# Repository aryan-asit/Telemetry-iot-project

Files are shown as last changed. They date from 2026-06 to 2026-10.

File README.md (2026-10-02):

# 4-Layer IoT Telemetry Board

A custom 4-layer IoT Telemetry Board designed from scratch using KiCad. The board is built around an ESP32 and integrates environmental sensing, local data storage, USB connectivity, wireless communication, and battery charging and power management in a compact PCB.

## Project Overview

The goal of this project was to design a compact and reliable IoT hardware platform capable of collecting environmental data, processing it locally, storing telemetry data, and communicating wirelessly.

The project covers the complete PCB development workflow, from component selection and schematic design to PCB layout, verification, 3D inspection, and manufacturing file generation.

## 3D PCB View

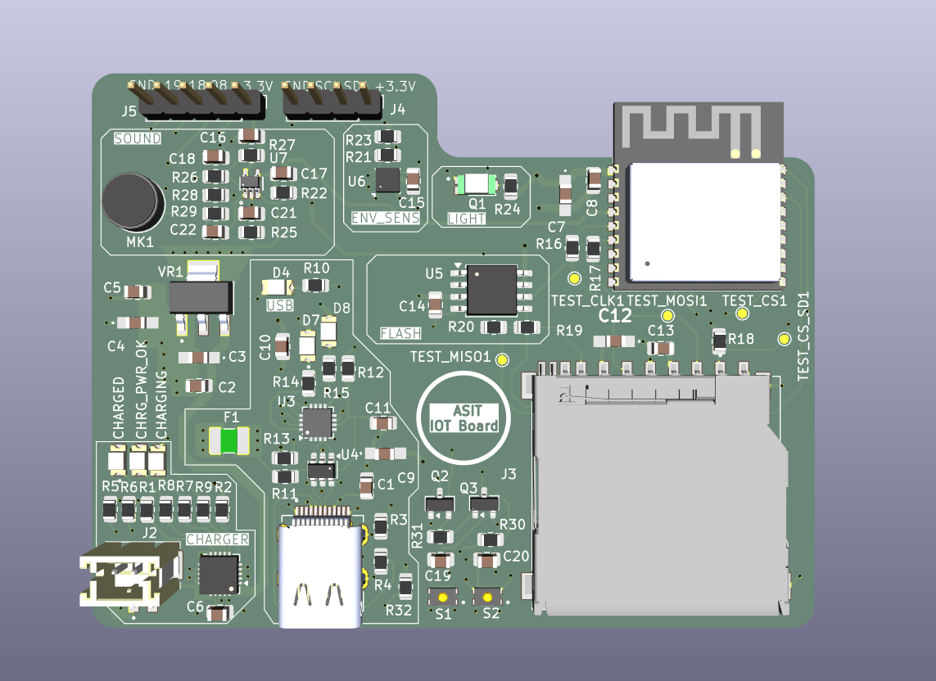
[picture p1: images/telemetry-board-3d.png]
3D View of ASIT IoT Board


## Key Features

### ESP32 Processing and Connectivity

The ESP32 is the main controller of the board and provides:

- Sensor data acquisition
- Local data processing
- Wi-Fi connectivity
- Bluetooth connectivity
- Communication with external peripherals

### Sensors

The board includes multiple sensing elements for environmental and acoustic monitoring:

- Microphone for sound sensing
- Humidity sensor for environmental monitoring
- Ambient light sensor for light-level measurement

### Data Storage

Two storage options are integrated into the board:

- Micro SD card for removable and higher-capacity data storage
- Flash memory for local non-volatile storage

### Power Management

The power section is based on the MCP73871 battery charging and power-management IC.

Main power features include:

- USB Type-C power input
- Battery charging
- Power-path management
- Battery-powered operation
- Dedicated 3.3 V regulation using an LM1117-3.3V regulator

### USB Type-C

A USB Type-C connector is included for power input and USB communication.

## PCB Stack-Up

The board uses a 4-layer PCB stack-up to improve power distribution, grounding, and routing flexibility.

| Layer | Purpose |
|---|---|
| Layer 1 | Signal |
| Layer 2 | Ground Plane |
| Layer 3 | Power Plane - 5 V and 3.3 V zones |
| Layer 4 | Signal |

The dedicated ground and power layers provide continuous return paths and simplify power distribution across the board.

## Communication Interfaces

| Interface | Purpose |
|---|---|
| I2C | Sensor and peripheral communication |
| SPI | SD card, flash memory, and other peripherals |
| USB | Power, programming, and communication |
| Wi-Fi | Wireless connectivity |
| Bluetooth | Short-range wireless connectivity |

## System Architecture

```text
                         +---------------------+
                         |     USB Type-C      |
                         |    Power / USB      |
                         +----------+----------+
                                    |
                                    v
                         +---------------------+
                         |      MCP73871       |
                         | Battery Charging &  |
                         |   Power Management  |
                         +----------+----------+
                                    |
                                    v
                         +---------------------+
                         |     LM1117-3.3V     |
                         |  Voltage Regulation |
                         +----------+----------+
                                    |
                                    v
                    +------------------------------+
                    |             ESP32            |
                    |      Processing & Control    |
                    |                              |
                    |       Wi-Fi + Bluetooth     |
                    +--------+----------+----------+
                             |          |
                 +-----------+----------+-----------+
                 |                      |           |
                 v                      v           v
          +-------------+       +-------------+ +---------+
          |   Sensors   |       |   Storage   | |  USB    |
          |             |       |             | | Type-C  |
          | Microphone  |       | Micro SD    | |         |
          | Humidity    |       | Flash       | |         |
          | Light       |       |             | |         |
          +-------------+       +-------------+ +---------+
```

## PCB Design Workflow

### 1. Concept Development

Defined the requirements for a compact IoT telemetry platform covering sensing, processing, storage, communication, and power management.

### 2. Component Selection

Selected the ESP32, sensors, memory devices, charging IC, regulator, connectors, and supporting components based on the system requirements.

### 3. Schematic Design

Designed and reviewed the complete circuit schematic and connected the individual functional blocks.

### 4. Footprint Selection and Creation

Selected suitable KiCad footprints and created or customized footprints where required.

### 5. PCB Layout

Defined the 4-layer stack-up and placed components while considering board size, routing complexity, signal paths, power distribution, and component accessibility.

### 6. Routing

Routed signal, power, and communication connections with attention to return paths, grounding, and clean power distribution.

### 7. 3D Verification

Configured 3D models and inspected the complete board to verify component placement and the overall physical arrangement.

### 8. ERC and DRC Verification

Performed Electrical Rules Check (ERC) and Design Rules Check (DRC) to identify and resolve schematic and PCB design issues.

### 9. Manufacturing Output

Generated Gerber and other required manufacturing files for PCB fabrication.

## Design Highlights

### 4-Layer PCB Design

The dedicated ground and power layers provide better power distribution and more flexible signal routing than a basic 2-layer approach.

### Integrated Power Management

The MCP73871 handles battery charging and power-path management, while the LM1117-3.3V provides a regulated 3.3 V supply for the low-voltage circuitry.

### Multiple Peripheral Interfaces

The board combines sensors, storage, USB, and wireless communication on a single PCB, making it suitable for different embedded and IoT applications.

### Compact Functional Layout

The component placement and routing were optimized to balance board size, functionality, accessibility, and routing complexity.

## Repository Contents

```text
Telemetry-iot-project/
|
+-- IOT_PCB/
|   +-- KiCad schematic and PCB design files
|
+-- images/
|   +-- telemetry-board-3d.png
|
+-- schematic files.pdf
|   +-- Complete schematic documentation
|
+-- Screenshot *.png
|   +-- PCB design and layout screenshots
|
+-- README.md
|   +-- Project documentation
```

## Tools and Technologies

### Hardware

- ESP32
- Microphone
- Humidity sensor
- Ambient light sensor
- Micro SD card
- Flash memory
- MCP73871
- LM1117-3.3V
- USB Type-C

### PCB Design

- KiCad v10
- Schematic Capture
- PCB Layout
- Footprint and Symbol Management
- 3D PCB Visualization
- ERC
- DRC
- Gerber Generation

### Communication

- I2C
- SPI
- USB
- Wi-Fi
- Bluetooth

## Applications

The board can be adapted for applications such as:

- Environmental monitoring
- IoT sensor nodes
- Wireless telemetry
- Data logging
- Noise monitoring
- Ambient light monitoring
- Smart embedded systems
- Battery-powered IoT devices
- Hardware prototyping

## What I Learned

This project provided practical experience in:

- 4-layer PCB design
- Schematic design and verification
- Component selection
- Footprint management
- PCB placement and routing
- Power distribution and grounding
- Signal-integrity considerations
- ERC and DRC debugging
- 3D PCB inspection
- Gerber generation
- Iterative hardware design and debugging

One of the main design challenges was finding the right balance between board size, routing complexity, power distribution, component placement, and overall functionality.

## Future Improvements

Possible future improvements include:

- Additional environmental sensors
- Cloud-based telemetry
- OTA firmware updates
- Improved power optimization
- Additional communication interfaces
- Dedicated debugging and programming features
- Enclosure and mechanical integration
- Web or mobile dashboard for telemetry visualization

## Author

**Aryan Asit**  
B.Tech - Electronics and Communication Engineering  
VLSI and Embedded Systems  
Indian Institute of Information Technology Manipur

## Repository

GitHub: https://github.com/aryan-asit/Telemetry-iot-project

## License

Refer to the repository license for usage and redistribution terms.

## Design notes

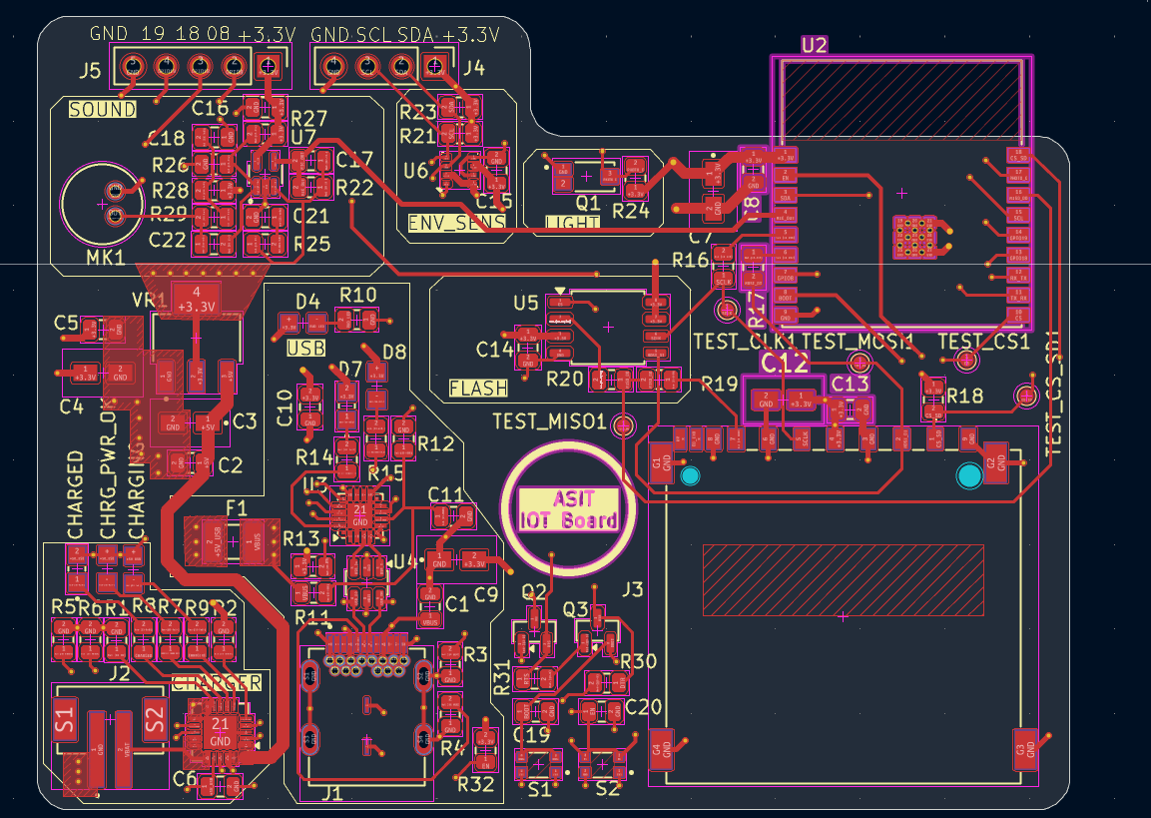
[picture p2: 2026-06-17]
images/Screenshot 2026-06-17 125201.png

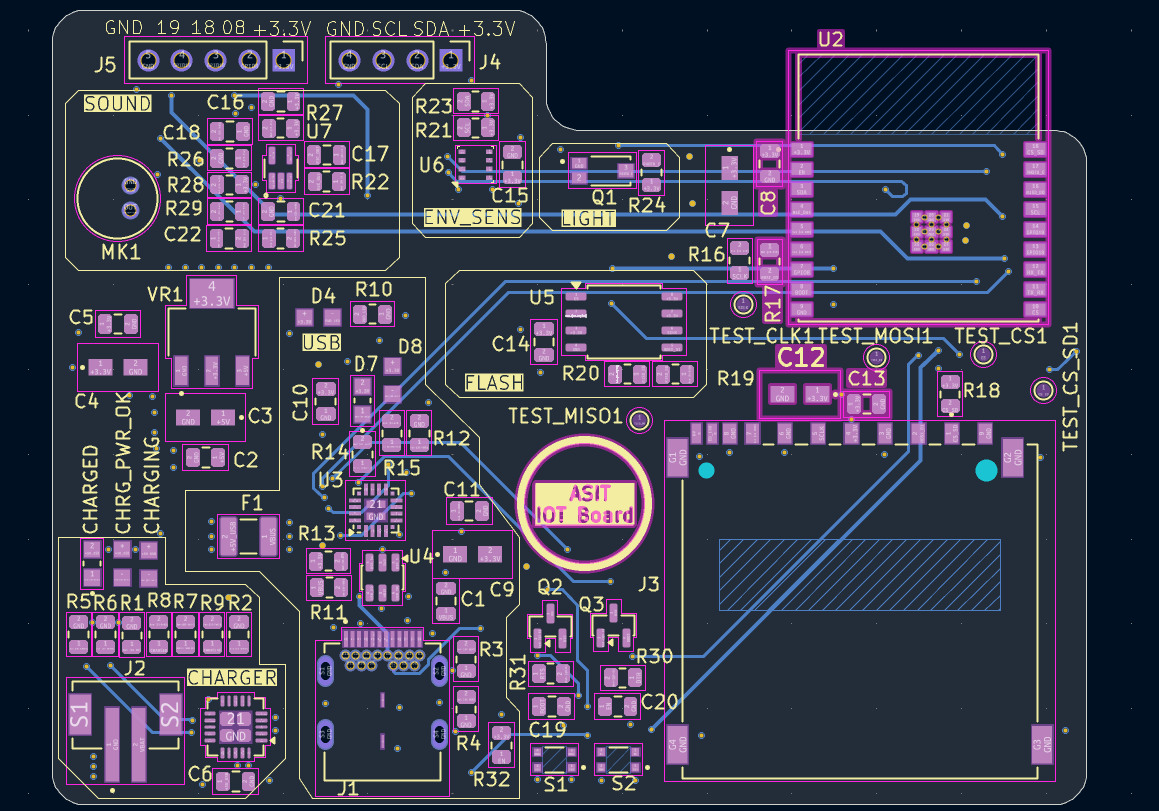
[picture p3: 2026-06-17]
images/Screenshot 2026-06-17 125239.png

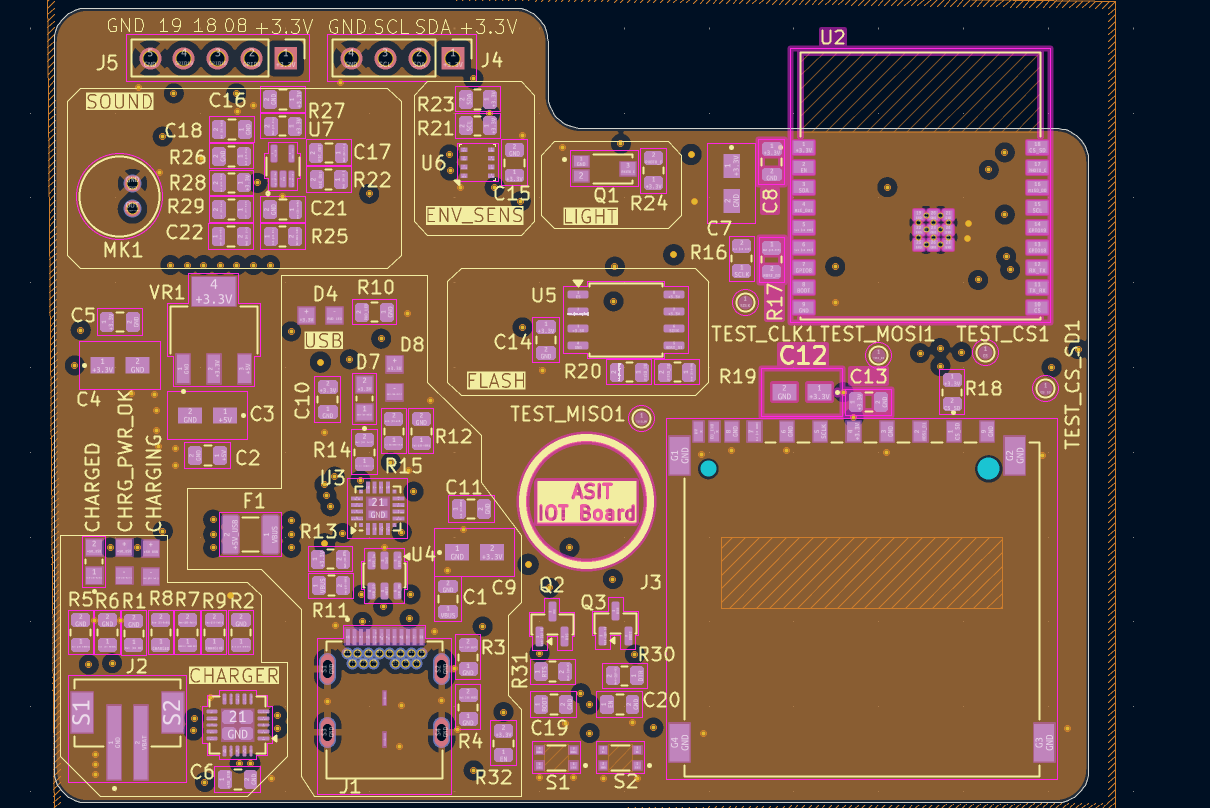
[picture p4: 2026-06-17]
images/Screenshot 2026-06-17 125227.png

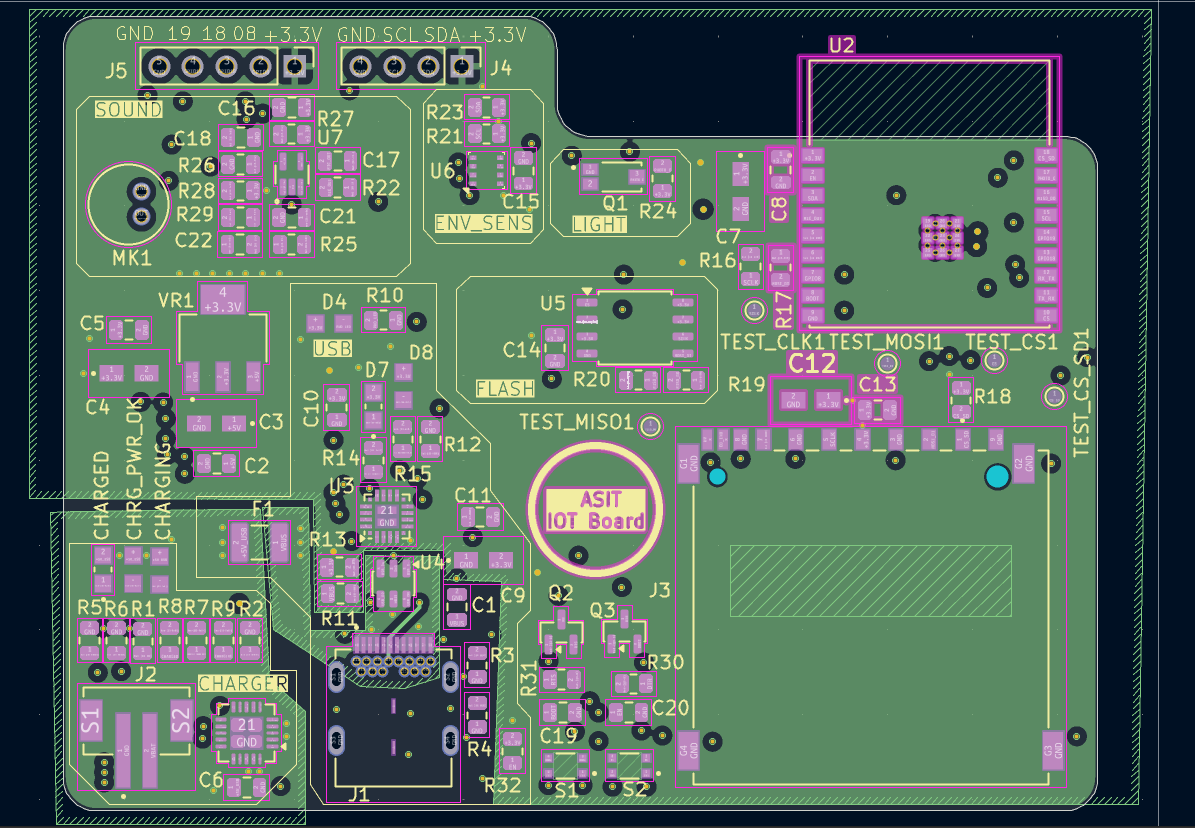
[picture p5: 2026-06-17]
images/Screenshot 2026-06-17 125213.png

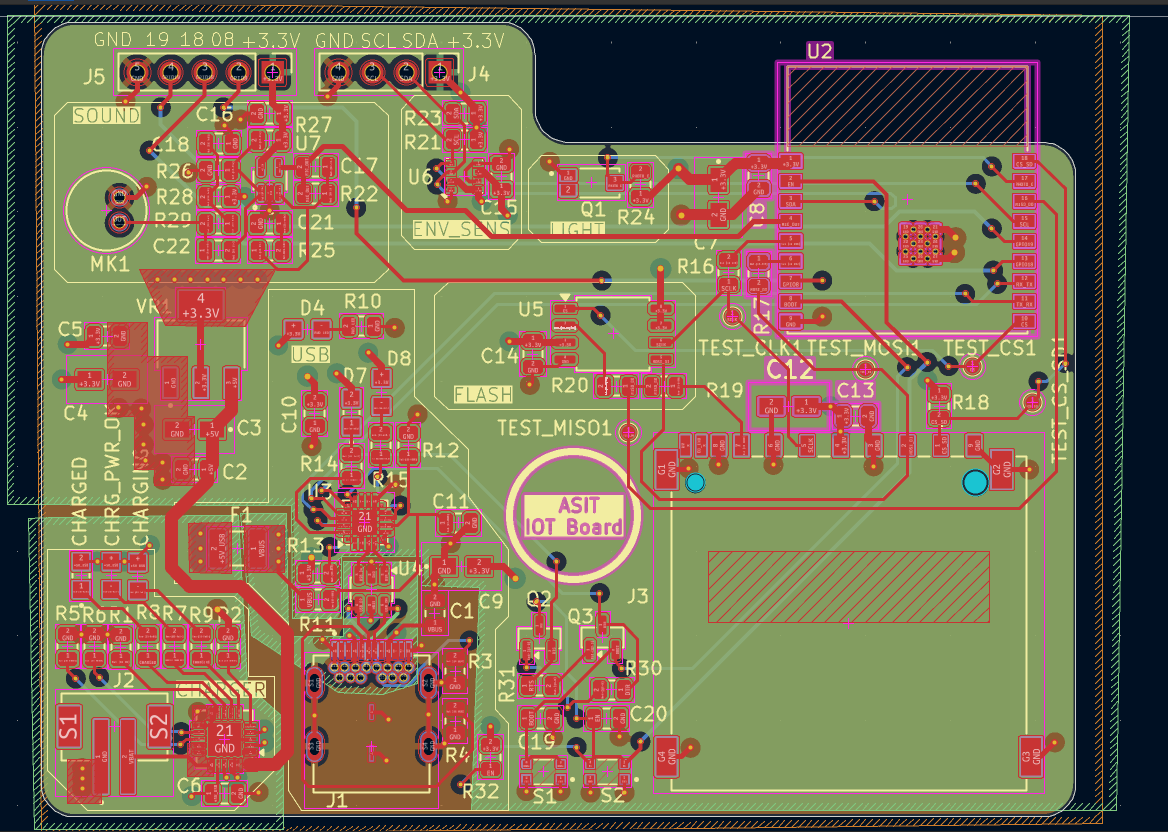
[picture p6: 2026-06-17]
images/Screenshot 2026-06-17 125148.png

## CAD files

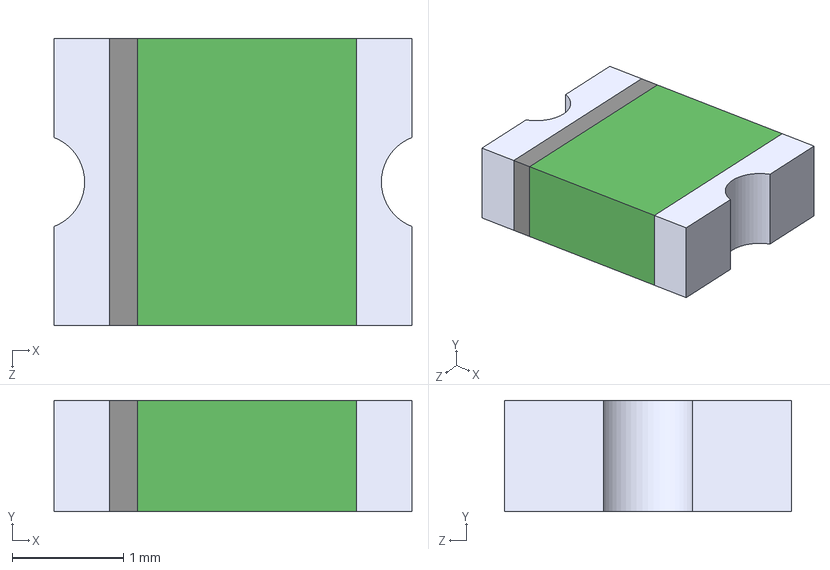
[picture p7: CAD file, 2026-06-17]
IOT_PCB/footprints_and_symbols/0ZCH0110AF2E/0ZCH0110AF2E.step
3.21 x 1.00 x 2.58 mm

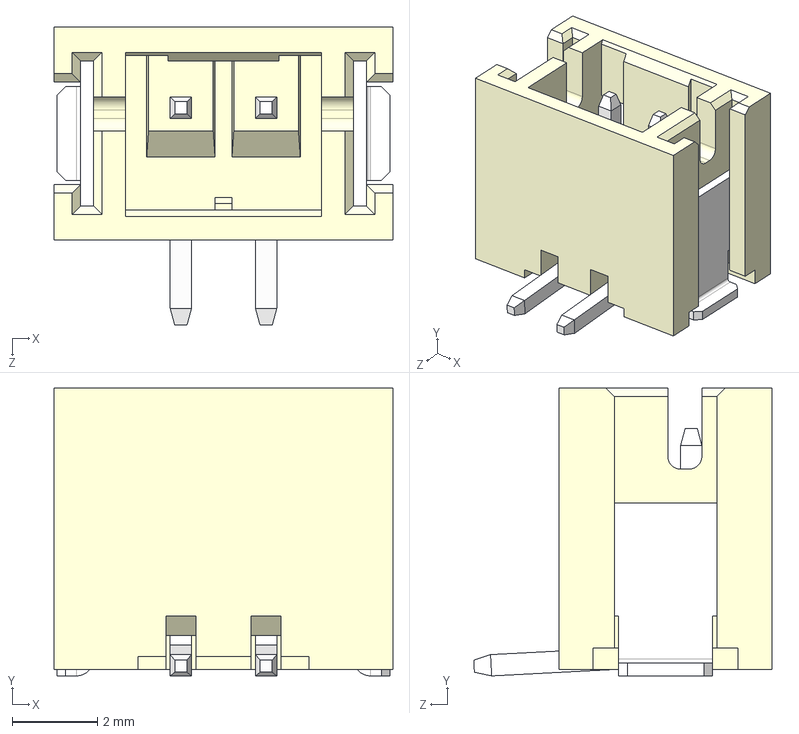
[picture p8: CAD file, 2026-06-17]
IOT_PCB/footprints_and_symbols/B2B-PH-SM4-TB/B2B-PH-SM4-TB.step
7.95 x 6.75 x 7.00 mm

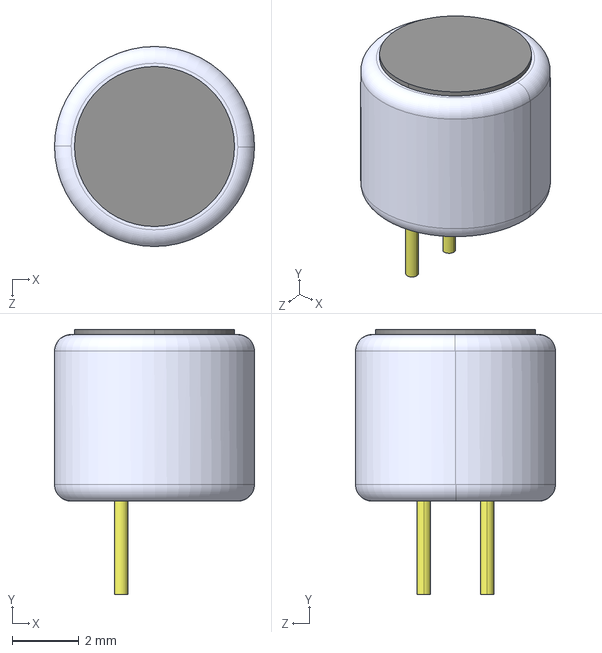
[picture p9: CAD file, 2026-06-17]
IOT_PCB/footprints_and_symbols/CMC-5042PF-AC/CMC-5042PF-AC.step
6.00 x 7.95 x 6.00 mm

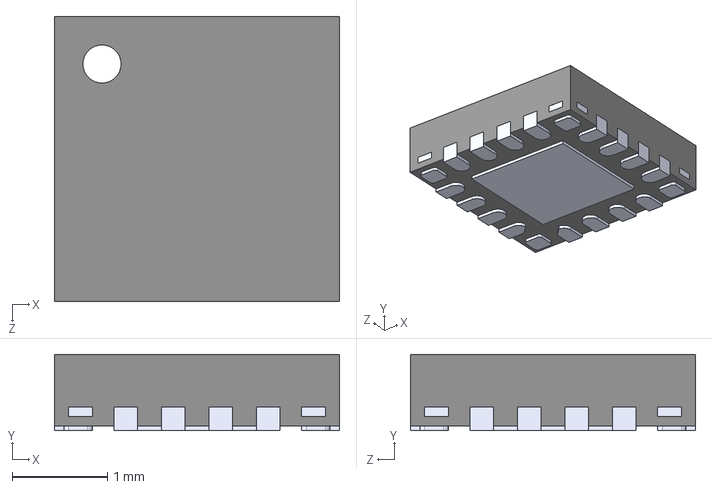
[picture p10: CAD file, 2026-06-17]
IOT_PCB/footprints_and_symbols/CP2102N-A02-GQFN20/CP2102N-A02-GQFN20.step
3.00 x 0.8 x 3.00 mm

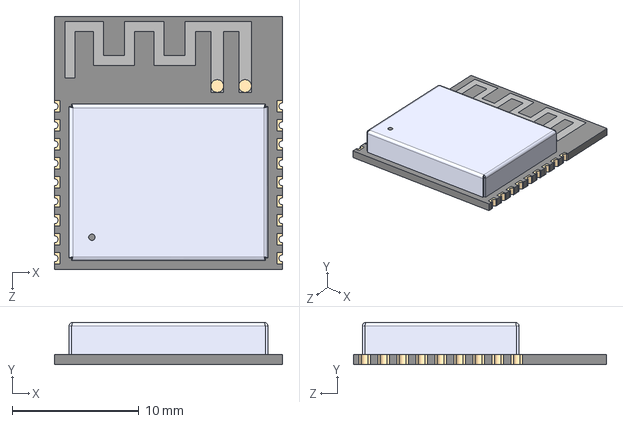
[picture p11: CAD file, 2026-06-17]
IOT_PCB/footprints_and_symbols/ESP32-C3-WROOM-02-H4/ESP32-C3-WROOM-02-H4.step
18.0 x 3.35 x 20.0 mm

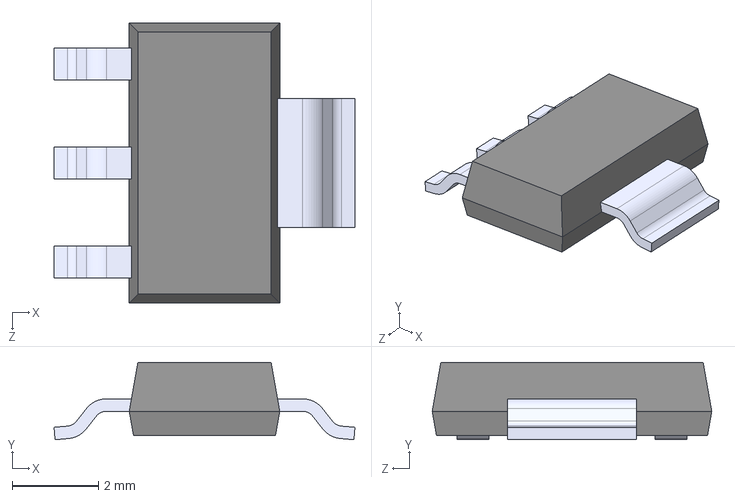
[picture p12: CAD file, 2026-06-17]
IOT_PCB/footprints_and_symbols/LM1117MPX-3.3/LM1117MPX-3.3.step
7.00 x 1.80 x 6.50 mm

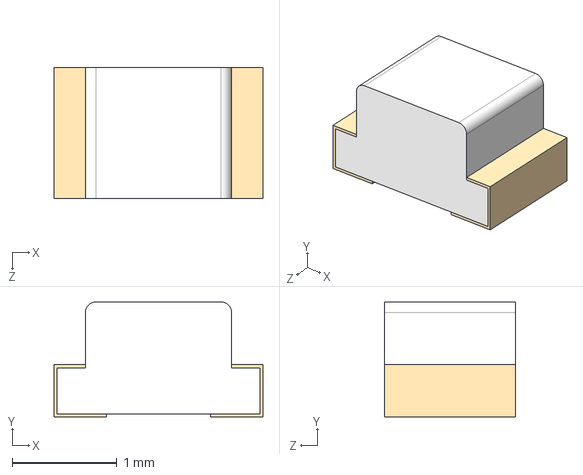
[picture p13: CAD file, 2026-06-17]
IOT_PCB/footprints_and_symbols/LTST-C170GKT/LTST-C170GKT.step
2.00 x 1.10 x 1.25 mm

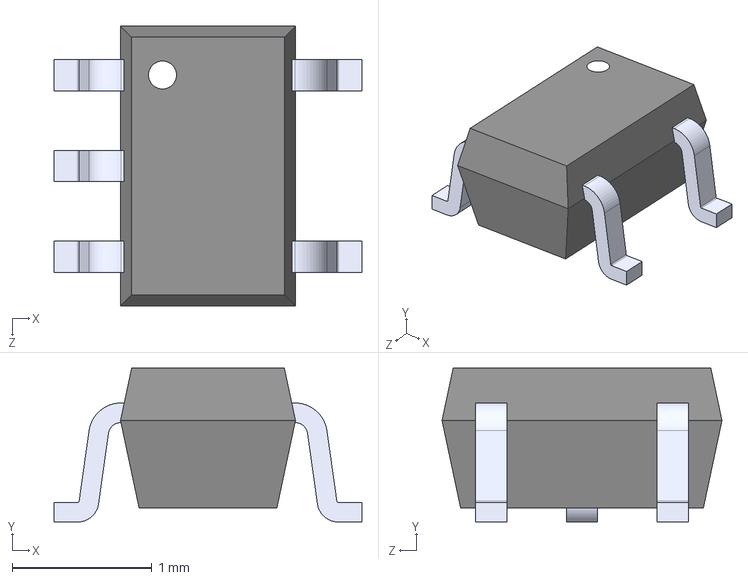
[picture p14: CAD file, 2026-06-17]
IOT_PCB/footprints_and_symbols/MAX4466EXK/MAX4466EXK.step
2.20 x 1.10 x 2.00 mm

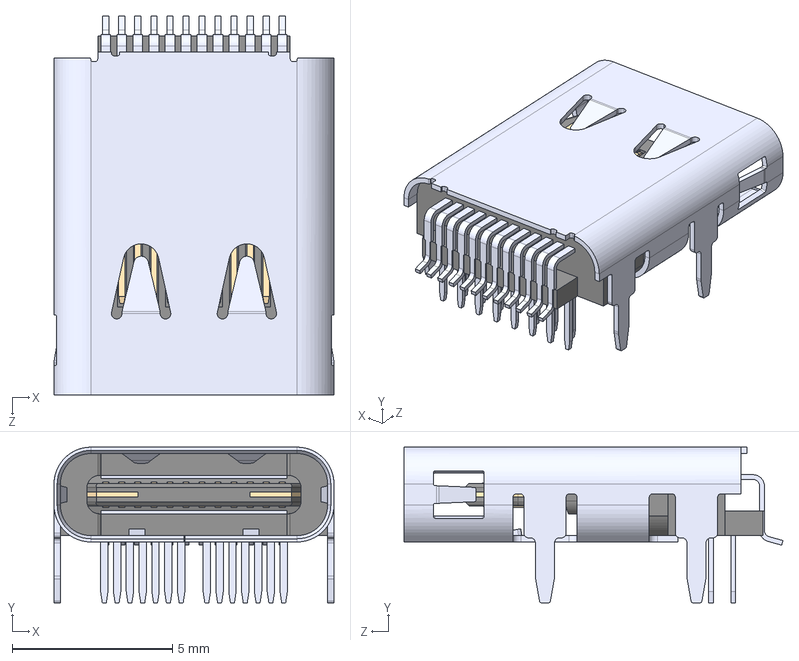
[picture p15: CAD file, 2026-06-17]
IOT_PCB/footprints_and_symbols/SS-52400-003/SS-52400-003.step
8.74 x 4.86 x 11.8 mm

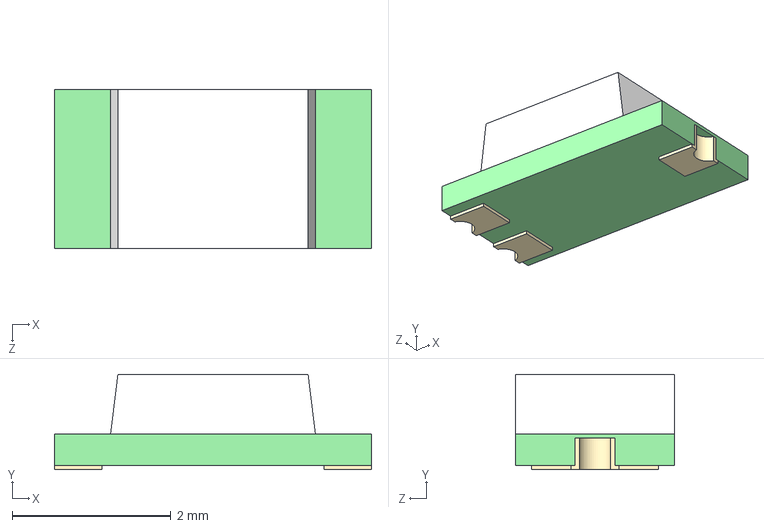
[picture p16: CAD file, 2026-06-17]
IOT_PCB/footprints_and_symbols/TEMT6000X01/TEMT6000X01.step
4.00 x 1.20 x 2.00 mm

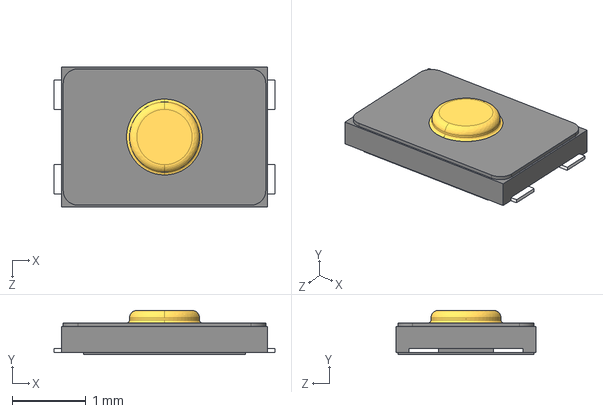
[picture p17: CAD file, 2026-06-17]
IOT_PCB/footprints_and_symbols/USLPT2819DT2TR/USLPT2819DT2TR.step
3.00 x 0.6 x 1.90 mm

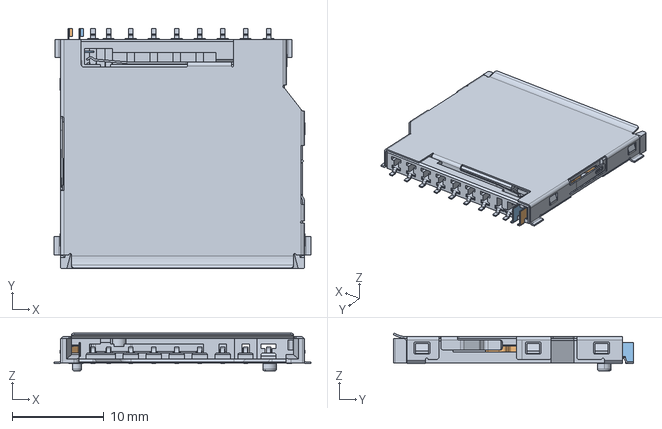
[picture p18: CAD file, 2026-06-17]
IOT_PCB/footprints_and_symbols/GSD090012SEU/GSD090012SEU.step
28.0 x 26.2 x 4.13 mm

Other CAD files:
IOT_PCB/footprints_and_symbols/LM1117MPX-3.3_NOPB/LM1117MPX-3.3_NOPB.step

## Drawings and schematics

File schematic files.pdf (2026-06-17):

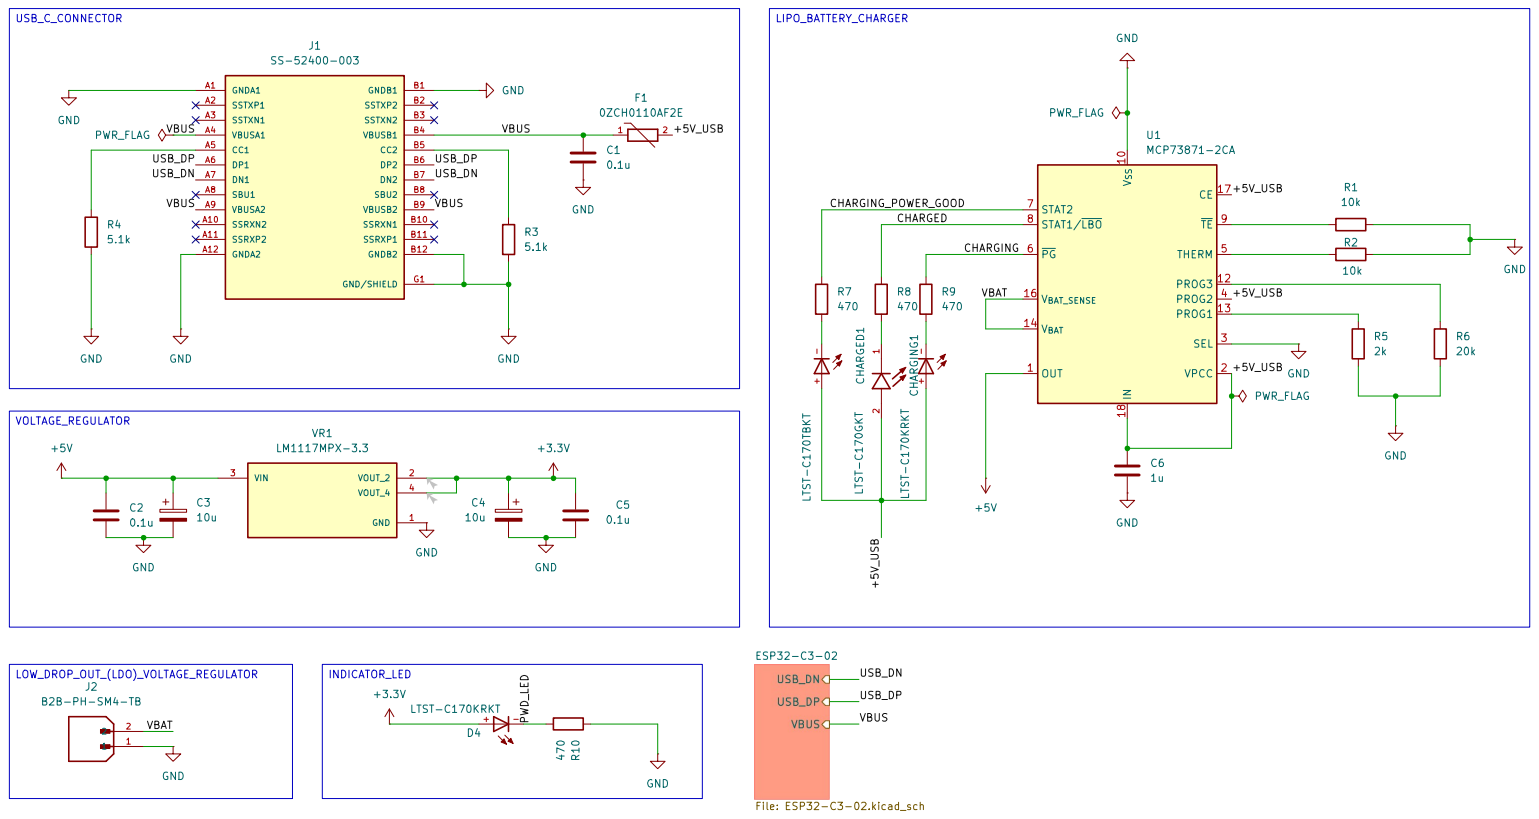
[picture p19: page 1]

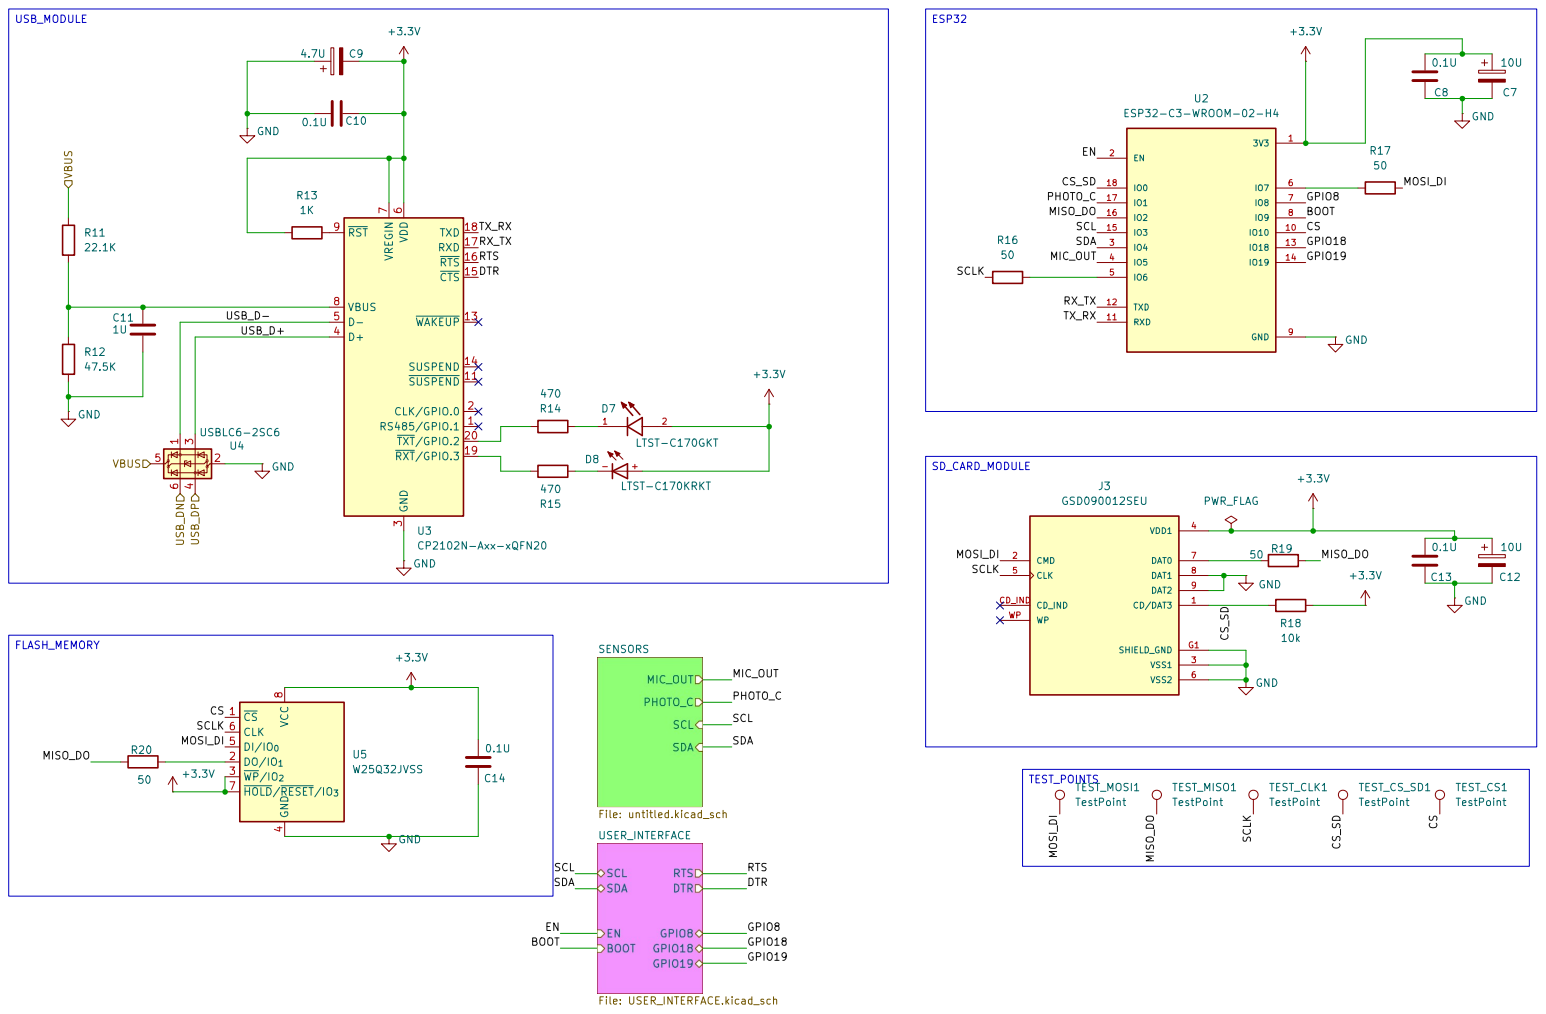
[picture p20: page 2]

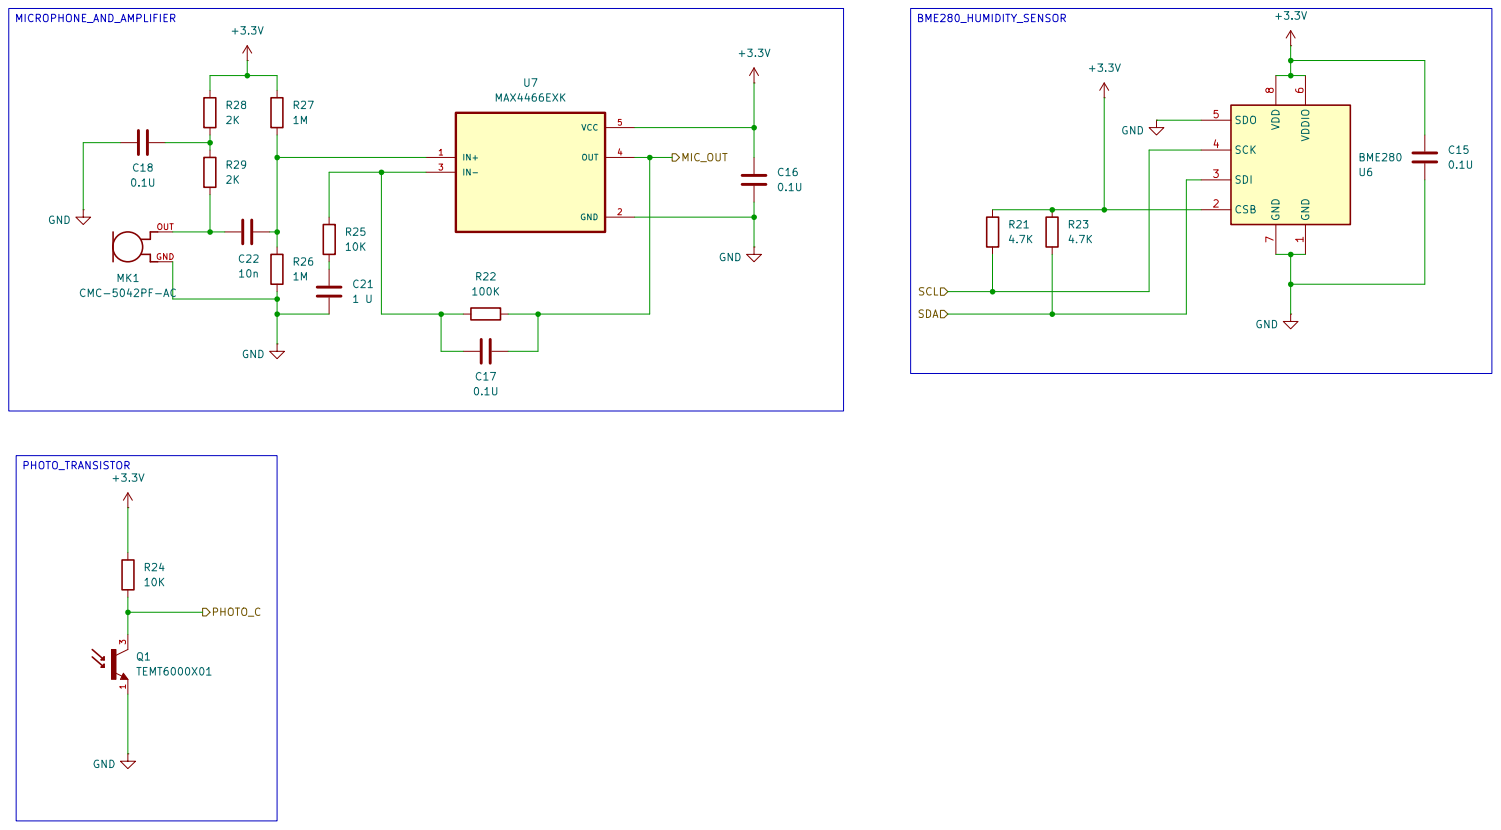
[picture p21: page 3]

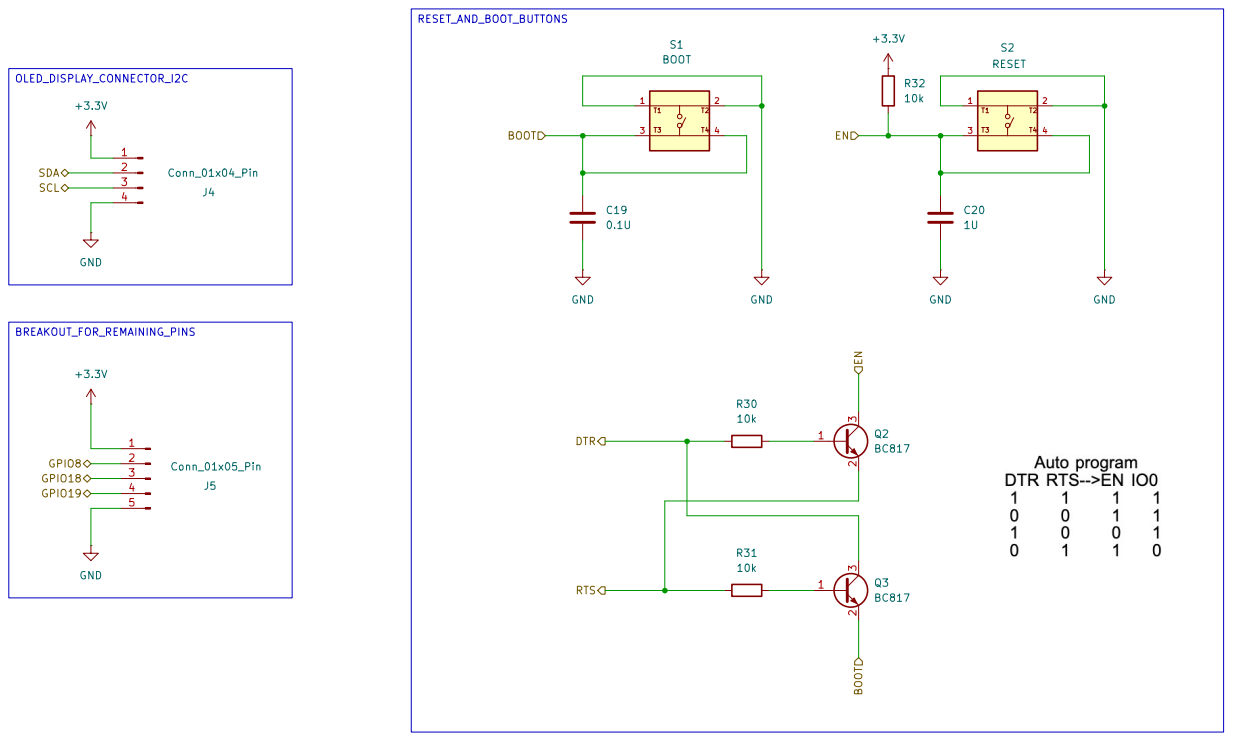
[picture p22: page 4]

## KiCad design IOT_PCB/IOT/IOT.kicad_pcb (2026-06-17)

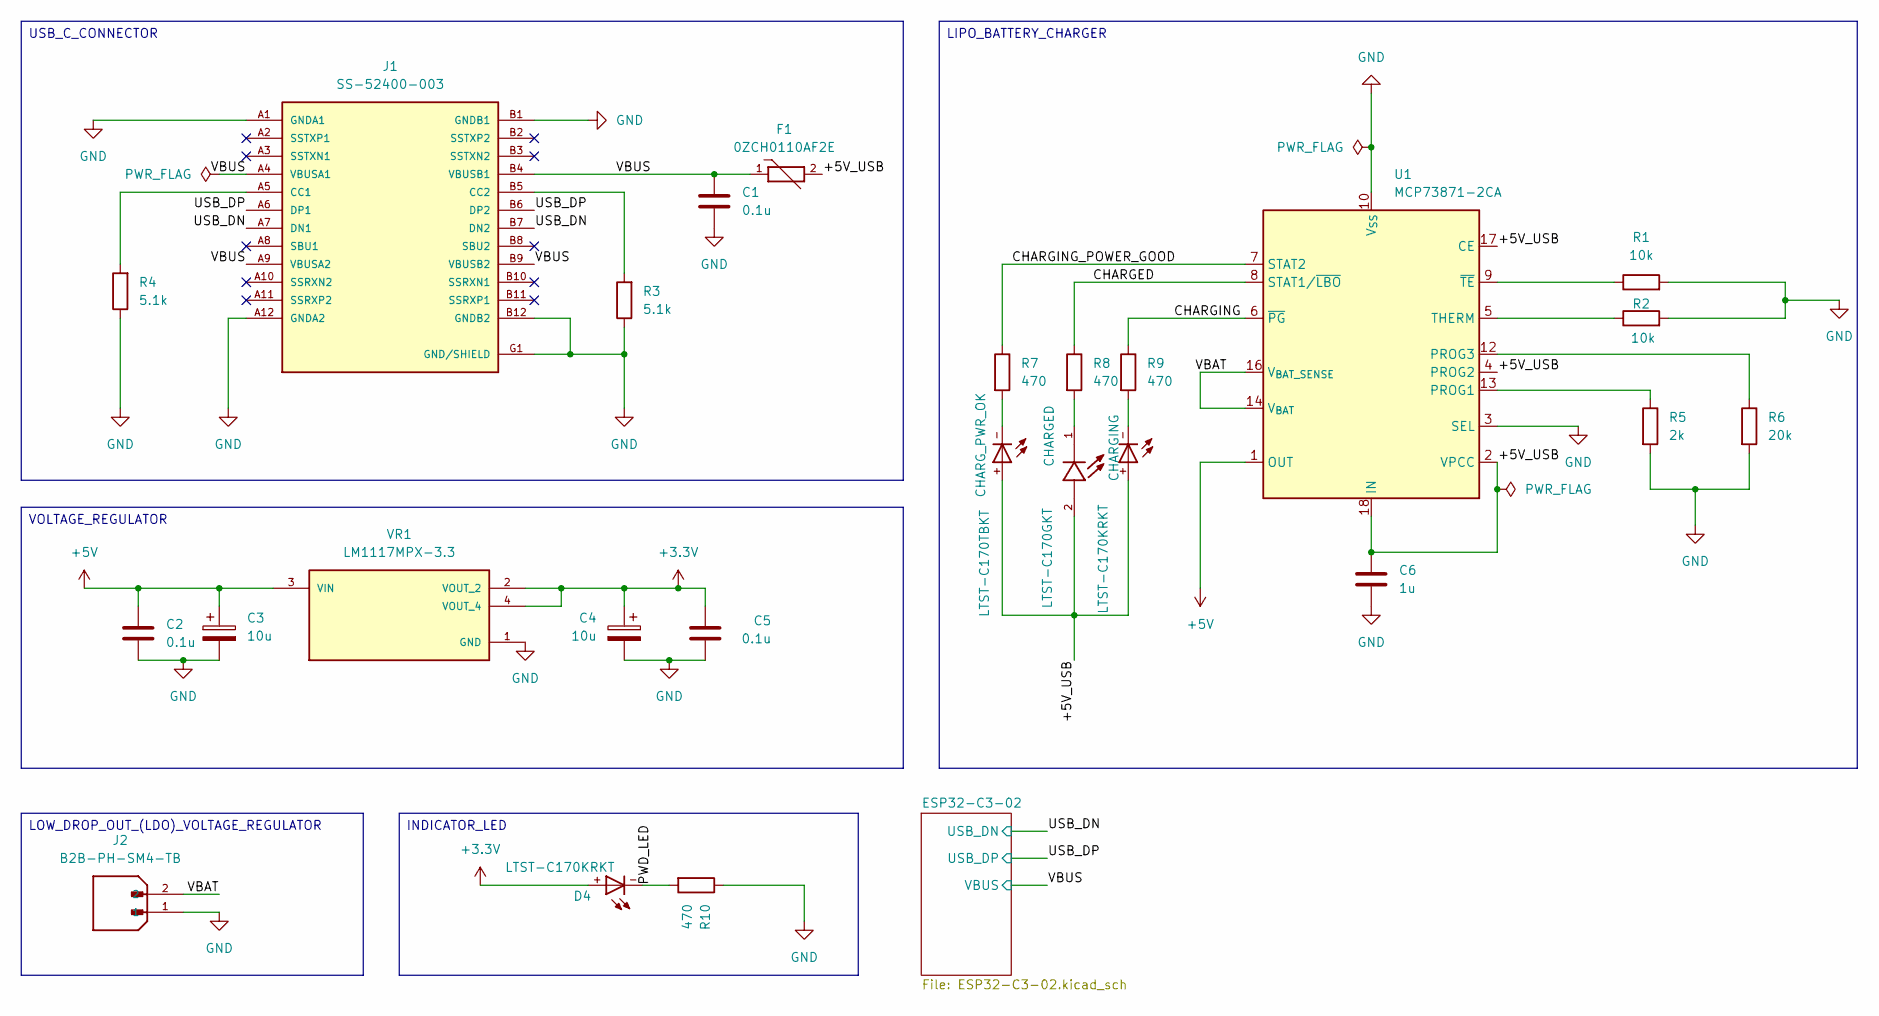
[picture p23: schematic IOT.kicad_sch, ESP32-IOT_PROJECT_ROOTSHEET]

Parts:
C1, C2, C5: 0.1u; C_0805_2012Metric
C3, C4: 10u; T491A
C6: 1u; C_0805_2012Metric
CHARGED: LTST-C170GKT; LED_LTST-C170GKT; PARTREV I
CHARGING: LTST-C170KRKT; DIOC200X125X110
CHARG_PWR_OK: LTST-C170TBKT; DIOC200X125X110
D4: LTST-C170KRKT; DIOC200X125X110
F1: 0ZCH0110AF2E; FUSC3225X100N; PARTREV Apr2023
J1: SS-52400-003; BELFUSE_SS-52400-003; PARTREV A0
J2: B2B-PH-SM4-TB; JST_B2B-PH-SM4-TB; PARTREV N/A
R1, R2: 10k; R_0805_2012Metric
R3, R4: 5.1k; R_0805_2012Metric
R5: 2k; R_0805_2012Metric
R6: 20k; R_0805_2012Metric
R7, R8, R9, R10: 470; R_0805_2012Metric
U1: MCP73871-2CA; QFN-20-1EP_4x4mm_P0.5mm_EP2.5x2.5mm
VR1: LM1117MPX-3.3; VREG_LM1117MPX-3.3; PARTREV O

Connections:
+3.3V: C4.1, C5.1, D4.+, VR1.2 (VOUT_2), VR1.4 (VOUT_4); also elsewhere on the board
+5V: C2.1, C3.1, U1.1 (OUT), U1.20 (OUT), VR1.3 (VIN)
/+5V_USB: C6.1, CHARGED.2, CHARGING.+, CHARG_PWR_OK.+, F1.2, U1.2 (VPCC), U1.4 (PROG2), U1.17 (CE), U1.18 (IN), U1.19 (IN); also elsewhere on the board
/CHARGED: R8.1, U1.8 (STAT1/~LBO)
/CHARGING: R9.1, U1.6 (~PG)
/CHARGING_POWER_GOOD: R7.1, U1.7 (STAT2)
/PWD_LED: D4.-, R10.2
/USB_DN: J1.A7 (DN1), J1.B7 (DN2); also elsewhere on the board
/USB_DP: J1.A6 (DP1), J1.B6 (DP2); also elsewhere on the board
/VBAT: J2.2, U1.14 (V_{BAT}), U1.15 (V_{BAT}), U1.16 (V_{BAT_SENSE})
/VBUS: C1.1, F1.1, J1.A4 (VBUSA1), J1.A9 (VBUSA2), J1.B4 (VBUSB1), J1.B9 (VBUSB2); also elsewhere on the board
GND: C1.2, C2.2, C3.2, C4.2, C5.2, C6.2, J1.A1 (GNDA1), J1.A12 (GNDA2), J1.B1 (GNDB1), J1.B12 (GNDB2), J1.G1 (GND/SHIELD), J1.G2 (GND/SHIELD), J1.G3 (GND/SHIELD), J1.G4 (GND/SHIELD), J1.S1 (GND/SHIELD), J1.S2 (GND/SHIELD), J1.S3 (GND/SHIELD), J1.S4 (GND/SHIELD), J2.1, R1.2, R2.2, R3.1, R4.1, R5.2, R6.2, R10.1, U1.3 (SEL), U1.10 (V_{SS}), U1.11 (V_{SS}), U1.21 (V_{SS}), VR1.1 (GND); also elsewhere on the board
unnamed: CHARGED.1, R8.2
unnamed 36: CHARG_PWR_OK.-, R7.2; also elsewhere on the board
unnamed: CHARGING.-, R9.2
unnamed: J1.A5 (CC1), R4.2
unnamed: J1.B5 (CC2), R3.2
unnamed: R5.1, U1.13 (PROG1)
unnamed: R6.1, U1.12 (PROG3)
unnamed: R2.1, U1.5 (THERM)
unnamed: R1.1, U1.9 (~TE)

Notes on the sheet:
USB_C_CONNECTOR
VOLTAGE_REGULATOR
LIPO_BATTERY_CHARGER
LOW_DROP_OUT_(LDO)_VOLTAGE_REGULATOR
INDICATOR_LED

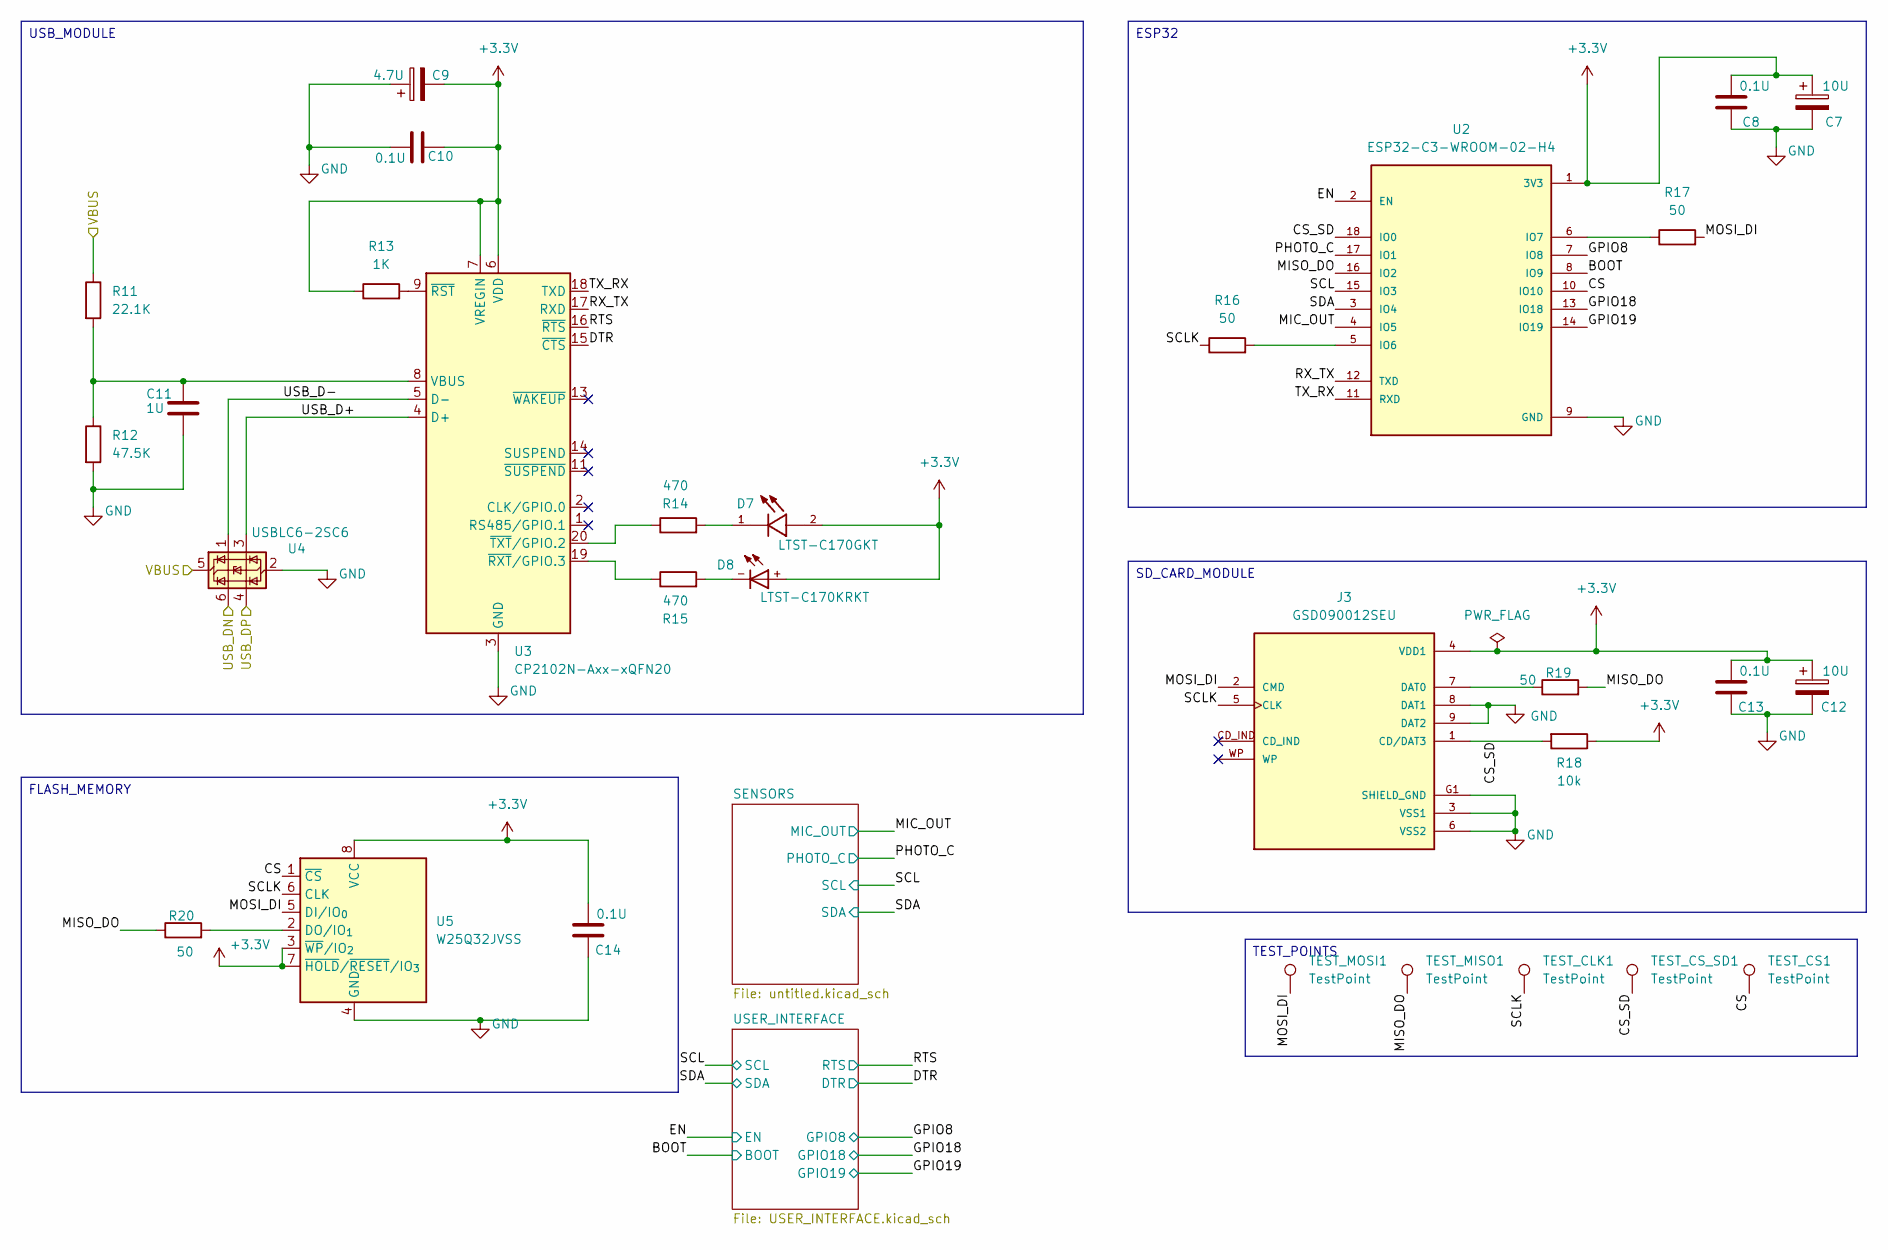
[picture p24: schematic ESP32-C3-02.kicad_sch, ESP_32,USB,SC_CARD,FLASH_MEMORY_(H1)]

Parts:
C7, C12: 10U; T491A
C8, C10, C13, C14: 0.1U; C_0805_2012Metric
C9: 4.7U; T491A
C11: 1U; C_0805_2012Metric
D7: LTST-C170GKT; LED_LTST-C170GKT; PARTREV I
D8: LTST-C170KRKT; DIOC200X125X110
J3: GSD090012SEU; AMPHENOL_GSD090012SEU; PARTREV E
R11: 22.1K; R_0805_2012Metric
R12: 47.5K; R_0805_2012Metric
R13: 1K; R_0805_2012Metric
R14, R15: 470; R_0805_2012Metric
R16, R17, R19, R20: 50; R_0805_2012Metric
R18: 10k; R_0805_2012Metric
TEST_CLK1: TestPoint; TestPoint_Pad_D1.0mm
TEST_CS1: TestPoint; TestPoint_Pad_D1.0mm
TEST_CS_SD1: TestPoint; TestPoint_Pad_D1.0mm
TEST_MISO1: TestPoint; TestPoint_Pad_D1.0mm
TEST_MOSI1: TestPoint; TestPoint_Pad_D1.0mm
U2: ESP32-C3-WROOM-02-H4; MODULE_ESP32-C3-WROOM-02-H4
U3: CP2102N-Axx-xQFN20; SiliconLabs_QFN-20-1EP_3x3mm_P0.5mm_EP1.8x1.8mm
U4: USBLC6-2SC6; SOT-23-6
U5: W25Q32JVSS; SOIC-8_5.3x5.3mm_P1.27mm

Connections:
+3.3V: C7.1, C8.1, C9.2, C10.2, C12.1, C13.1, C14.1, D7.2, D8.+, J3.4 (VDD1), R13.1, R18.1, U2.1 (3V3), U3.6 (VDD), U3.7 (VREGIN), U5.3 (~WP/IO_{2}), U5.7 (~HOLD/~RESET/IO_{3}), U5.8 (VCC); also elsewhere on the board
/ESP32-C3-02/BOOT: U2.8 (IO9); also elsewhere on the board
/ESP32-C3-02/CS: TEST_CS1.1 (1_1), U2.10 (IO10), U5.1 (~CS)
/ESP32-C3-02/CS_SD: J3.1 (CD/DAT3), R18.2, TEST_CS_SD1.1 (1_1), U2.18 (IO0)
/ESP32-C3-02/DTR: U3.15 (~CTS); also elsewhere on the board
/ESP32-C3-02/EN: U2.2 (EN); also elsewhere on the board
/ESP32-C3-02/GPIO8: U2.7 (IO8); also elsewhere on the board
/ESP32-C3-02/GPIO18: U2.13 (IO18); also elsewhere on the board
/ESP32-C3-02/GPIO19: U2.14 (IO19); also elsewhere on the board
/ESP32-C3-02/MIC_OUT: U2.4 (IO5); also elsewhere on the board
/ESP32-C3-02/MISO_DO: R19.2, R20.1, TEST_MISO1.1 (1_1), U2.16 (IO2)
/ESP32-C3-02/MOSI_DI: J3.2 (CMD), R17.2, TEST_MOSI1.1 (1_1), U5.5 (DI/IO_{0})
/ESP32-C3-02/PHOTO_C: U2.17 (IO1); also elsewhere on the board
/ESP32-C3-02/RTS: U3.16 (~RTS); also elsewhere on the board
/ESP32-C3-02/RX_TX: U2.12 (TXD), U3.17 (RXD)
/ESP32-C3-02/SCL: U2.15 (IO3); also elsewhere on the board
/ESP32-C3-02/SCLK: J3.5 (CLK), R16.1, TEST_CLK1.1 (1_1), U5.6 (CLK)
/ESP32-C3-02/SDA: U2.3 (IO4); also elsewhere on the board
/ESP32-C3-02/TX_RX: U2.11 (RXD), U3.18 (TXD)
/ESP32-C3-02/USB_D+: U3.4 (D+), U4.3 (I/O2)
/ESP32-C3-02/USB_D-: U3.5 (D-), U4.1 (I/O1)
/USB_DN: U4.6 (I/O1); also elsewhere on the board
/USB_DP: U4.4 (I/O2); also elsewhere on the board
/VBUS: R11.1, U4.5 (VBUS); also elsewhere on the board
GND: C7.2, C8.2, C9.1, C10.1, C11.2, C12.2, C13.2, C14.2, J3.3 (VSS1), J3.6 (VSS2), J3.8 (DAT1), J3.9 (DAT2), J3.G1 (SHIELD_GND), J3.G2 (SHIELD_GND), J3.G3 (SHIELD_GND), J3.G4 (SHIELD_GND), R12.2, U2.9 (GND), U2.19 (GND), U2.20 (GND), U2.21 (GND), U2.22 (GND), U2.23 (GND), U2.24 (GND), U2.25 (GND), U2.26 (GND), U2.27 (GND), U2.28 (GND), U2.29 (GND), U2.30 (GND), U2.31 (GND), U2.32 (GND), U2.33 (GND), U2.34 (GND), U2.35 (GND), U2.36 (GND), U2.37 (GND), U2.38 (GND), U2.39 (GND), U3.3 (GND), U3.12 (GND), U3.21 (GND), U4.2 (GND), U5.4 (GND); also elsewhere on the board
unnamed: D7.1, R14.2
unnamed: D8.-, R15.2
unnamed: J3.7 (DAT0), R19.1
unnamed: R16.2, U2.5 (IO6)
unnamed: R17.1, U2.6 (IO7)
unnamed: C11.1, R11.2, R12.1, U3.8 (VBUS)
unnamed: R13.2, U3.9 (~RST)
unnamed: R15.1, U3.19 (~RXT/GPIO.3)
unnamed: R14.1, U3.20 (~TXT/GPIO.2)
unnamed: R20.2, U5.2 (DO/IO_{1})

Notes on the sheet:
USB_MODULE
FLASH_MEMORY
SD_CARD_MODULE
TEST_POINTS
ESP32

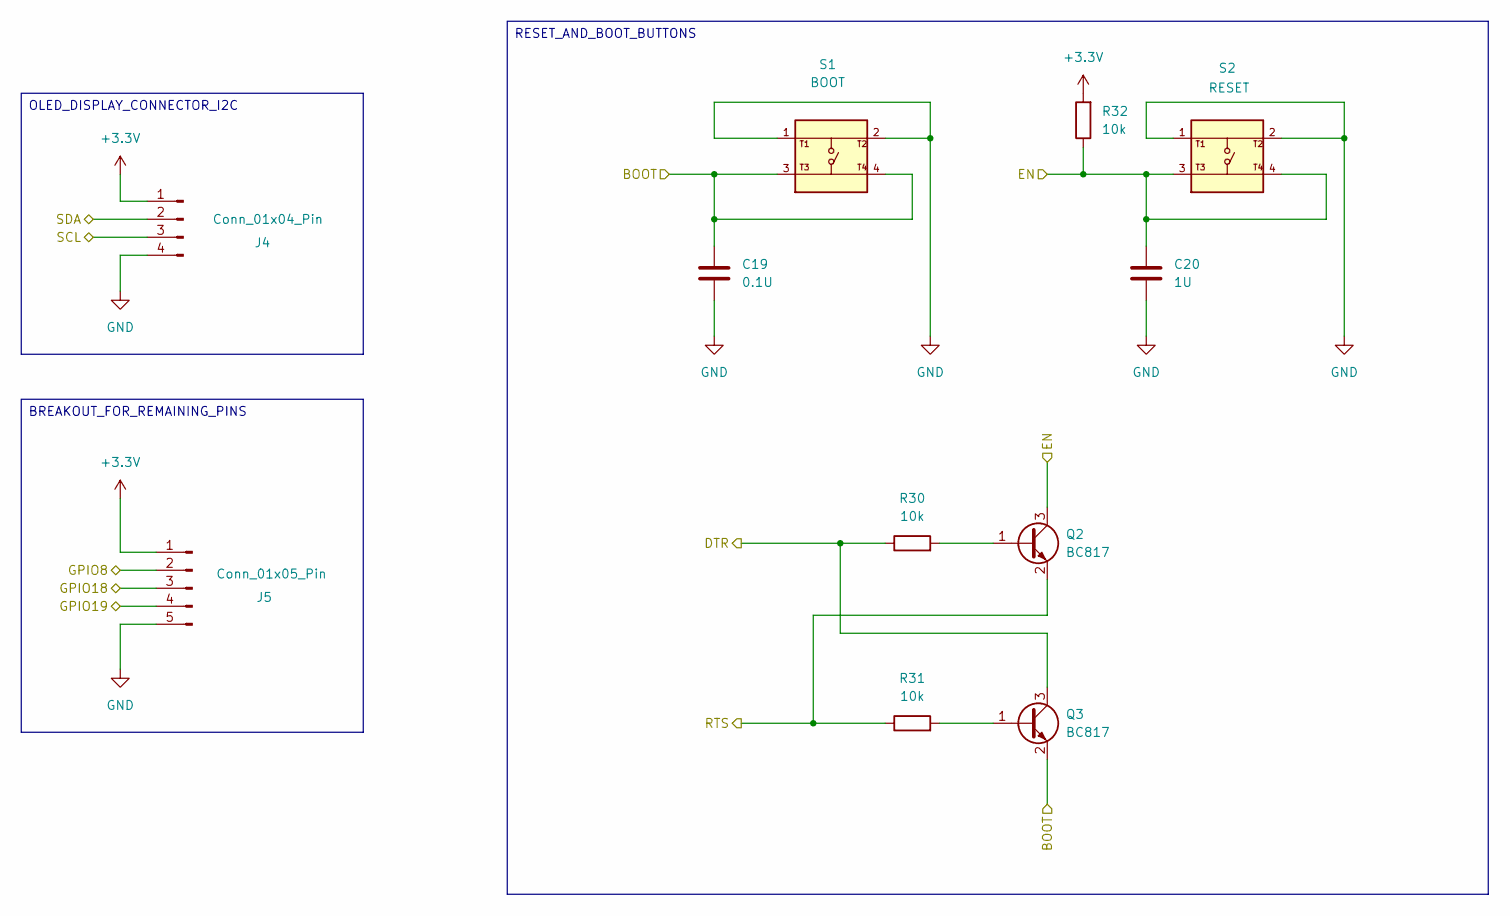
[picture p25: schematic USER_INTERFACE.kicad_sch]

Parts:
C19: 0.1U; C_0805_2012Metric
C20: 1U; C_0805_2012Metric
J4: Conn_01x04_Pin; PinHeader_1x04_P2.54mm_Vertical
J5: Conn_01x05_Pin; PinHeader_1x05_P2.54mm_Vertical
Q2, Q3: BC817; SOT-23
R30, R31, R32: 10k; R_0805_2012Metric
S1: BOOT; SW_USLPT2819DT2TR; PARTREV P
S2: RESET; SW_USLPT2819DT2TR; PARTREV P

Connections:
+3.3V: J4.1, J5.1, R32.2; also elsewhere on the board
/ESP32-C3-02/BOOT: C19.1, Q3.2 (E), S1.3, S1.4; also elsewhere on the board
/ESP32-C3-02/DTR: Q3.3 (C), R30.1; also elsewhere on the board
/ESP32-C3-02/EN: C20.1, Q2.3 (C), R32.1, S2.3, S2.4; also elsewhere on the board
/ESP32-C3-02/GPIO8: J5.2; also elsewhere on the board
/ESP32-C3-02/GPIO18: J5.3; also elsewhere on the board
/ESP32-C3-02/GPIO19: J5.4; also elsewhere on the board
/ESP32-C3-02/RTS: Q2.2 (E), R31.1; also elsewhere on the board
/ESP32-C3-02/SCL: J4.3; also elsewhere on the board
/ESP32-C3-02/SDA: J4.2; also elsewhere on the board
GND: C19.2, C20.2, J4.4, J5.5, S1.1, S1.2, S2.1, S2.2; also elsewhere on the board
unnamed: Q2.1 (B), R30.2
unnamed: Q3.1 (B), R31.2

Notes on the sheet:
RESET_AND_BOOT_BUTTONS
BREAKOUT_FOR_REMAINING_PINS
OLED_DISPLAY_CONNECTOR_I2C

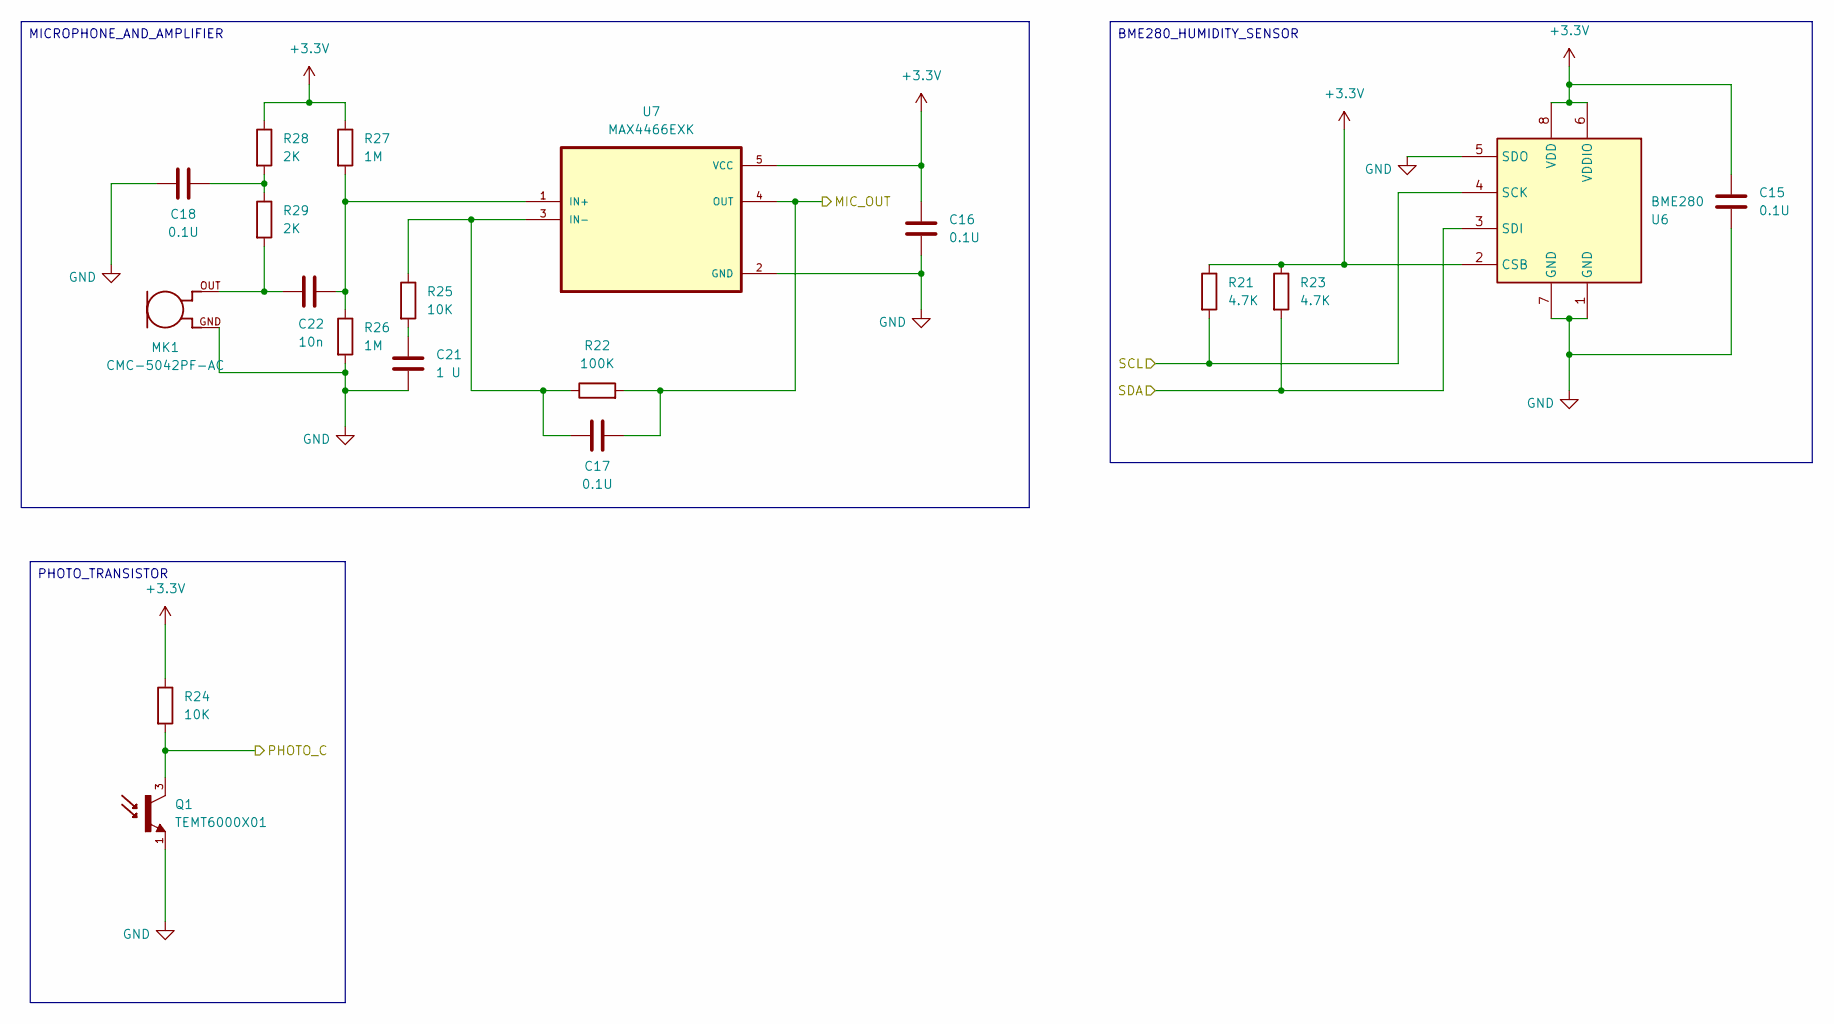
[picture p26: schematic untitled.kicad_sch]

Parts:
C15, C16, C17, C18: 0.1U; C_0805_2012Metric
C21: 1 U; C_0805_2012Metric
C22: 10n; C_0805_2012Metric
MK1: CMC-5042PF-AC; CUI_CMC-5042PF-AC
Q1: TEMT6000X01; TRANS_TEMT6000X01; PARTREV 1.9
R21, R23: 4.7K; R_0805_2012Metric
R22: 100K; R_0805_2012Metric
R24, R25: 10K; R_0805_2012Metric
R26, R27: 1M; R_0805_2012Metric
R28, R29: 2K; R_0805_2012Metric
U6: BME280; Bosch_LGA-8_2.5x2.5mm_P0.65mm_ClockwisePinNumbering
U7: MAX4466EXK; SOT65P210X110-5N

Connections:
+3.3V: C15.1, C16.1, R21.1, R23.1, R24.1, R27.1, R28.1, U6.2 (CSB), U6.6 (VDDIO), U6.8 (VDD), U7.5 (VCC); also elsewhere on the board
/ESP32-C3-02/MIC_OUT: C17.2, R22.2, U7.4 (OUT); also elsewhere on the board
/ESP32-C3-02/PHOTO_C: Q1.3, R24.2; also elsewhere on the board
/ESP32-C3-02/SCL: R21.2, U6.4 (SCK); also elsewhere on the board
/ESP32-C3-02/SDA: R23.2, U6.3 (SDI); also elsewhere on the board
GND: C15.2, C16.2, C18.1, C21.2, MK1.GND, Q1.1, R26.2, U6.1 (GND), U6.5 (SDO), U6.7 (GND), U7.2 (GND); also elsewhere on the board
unnamed: C18.2, R28.2, R29.1
unnamed: C21.1, R25.2
unnamed: C22.1, MK1.OUT, R29.2
unnamed: C22.2, R26.1, R27.2, U7.1 (IN+)
unnamed: C17.1, R22.1, R25.1, U7.3 (IN-)

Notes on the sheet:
BME280_HUMIDITY_SENSOR
PHOTO_TRANSISTOR
MICROPHONE_AND_AMPLIFIER

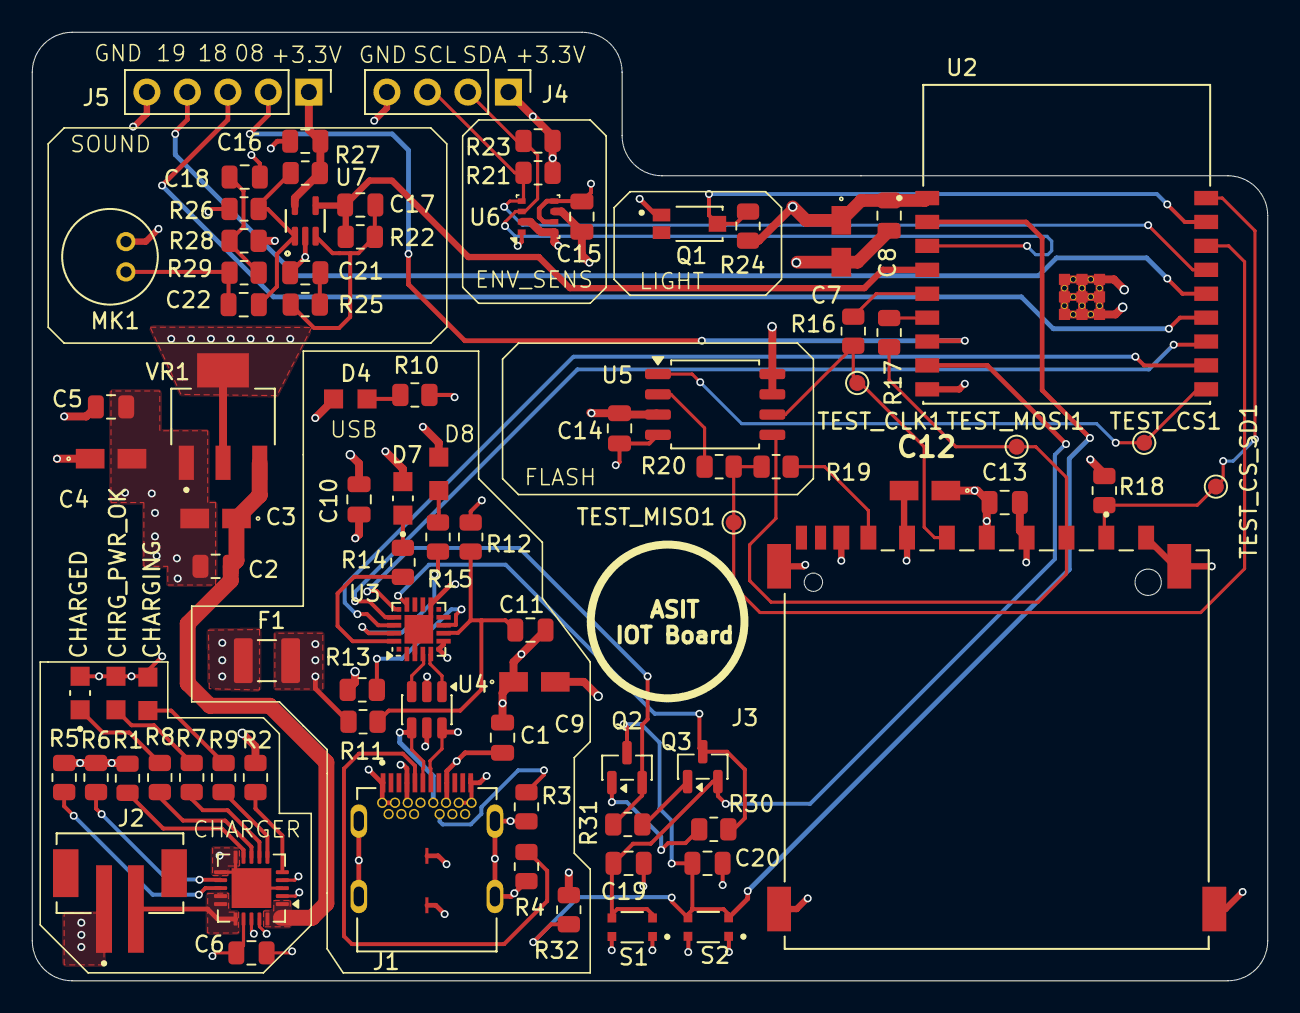
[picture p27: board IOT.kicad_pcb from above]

Board: 4 copper layers, 77.5 x 59.5 mm, 85 parts (0 on the bottom side), 58 nets.

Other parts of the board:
CHRG_PWR_OK: LTST-C170TBKT; DIOC200X125X110

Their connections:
/+5V_USB: CHRG_PWR_OK.+; also elsewhere on the board
unnamed 36: CHRG_PWR_OK.-; also elsewhere on the board
